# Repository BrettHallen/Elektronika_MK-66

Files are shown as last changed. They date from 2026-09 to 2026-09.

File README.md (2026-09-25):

# Elektronika MK-66<br>Электроника МК-66
Information about the Soviet-era engineering "microcalculator".<br>

Processor: [К145ИП16Б](/K145IP16B/)<br>
Display: [ИЛЦ2-12/8Л](/ILC2-12_8L)<br>
Keypad: 5x5 metal-dome matrix<br>

## DEAR COMRADE!
You are now the owner of a domestically made microcalculator.<br>
A microcalculator is a miniature electronic computing device for personal use.<br>
Careful handling of the microcalculator, tidiness and compliance with the requirements of this operating manual will ensure its reliable operation for a long time.<br>
We are confident that the microcalculator will be a reliable helper in your mathematical calculations.<br>
The manufacturer’s engineers are continually working to improve the technical and operating characteristics of the microcalculator and will be grateful for your feedback on its performance.<br>

## Keypad Layout

The MK-66 has 25 keys in a 5 × 5 matrix, plus two slide switches above the keys. Each key has a **primary function**, printed on the key, and a *second function*, printed on the panel above it. To use a second function, press **F** first, then the key.

### Switches

| Position | Marking | Function |
|:--|:--|:--|
| Left | `•` | **Power**: slide right (towards the dot) for on, left for off |
| Right | `Г` / `Р` | **Angle mode**: Г = degrees (*градусы*), Р = radians (*радианы*). MK-66 only; the MK-66A works in degrees only |

### Original markings

Each cell shows the *second function* above the **key**.

| | Col 1 | Col 2 | Col 3 | Col 4 | Col 5 |
|:-:|:-:|:-:|:-:|:-:|:-:|
| **Row 1** | *CF*<br>**C** | *1/X*<br>**/-/** | &nbsp;<br>**arc** | &nbsp;<br>**ВП** | &nbsp;<br>**F** |
| **Row 2** | *eˣ*<br>**7** | *10ˣ*<br>**8** | *yˣ*<br>**9** | *ЗП*<br>**[(** | *СП*<br>**)]** |
| **Row 3** | *ln*<br>**4** | *lg*<br>**5** | *√*<br>**6** | *П×*<br>**×** | *П÷*<br>**÷** |
| **Row 4** | *sin*<br>**1** | *cos*<br>**2** | *tg*<br>**3** | *П+*<br>**+** | *П−*<br>**−** |
| **Row 5** | *Р→Г*<br>**0** | *Г→Р*<br>**.** | *n!*<br>**π** | *Х↔П*<br>**↔** | *ИП*<br>**=** |

### English equivalents

| | Col 1 | Col 2 | Col 3 | Col 4 | Col 5 |
|:-:|:-:|:-:|:-:|:-:|:-:|
| **Row 1** | *Cancel F*<br>**Clear** | *1/x*<br>**+/−** | &nbsp;<br>**Inverse (arc)** | &nbsp;<br>**EE / EXP** | &nbsp;<br>**Function** |
| **Row 2** | *eˣ*<br>**7** | *10ˣ*<br>**8** | *yˣ*<br>**9** | *MS*<br>**(** | *MC*<br>**)** |
| **Row 3** | *ln*<br>**4** | *log*<br>**5** | *√x*<br>**6** | *M×*<br>**×** | *M÷*<br>**÷** |
| **Row 4** | *sin*<br>**1** | *cos*<br>**2** | *tan*<br>**3** | *M+*<br>**+** | *M−*<br>**−** |
| **Row 5** | *rad→deg*<br>**0** | *deg→rad*<br>**.** | *n!*<br>**π** | *X↔M*<br>**X↔Y** | *MR*<br>**=** |

### Key reference

| Marking | Russian | English | Notes |
|:--|:--|:--|:--|
| **C** | — | Clear | Once: clears overflow. In F mode, press 3×: cancel F, clear display, clear constant register. Does not clear memory |
| *CF* | — | Cancel F | Leaves dual-function mode |
| **/-/** | — | Change sign (+/−) | Changes the sign of the mantissa, or of the exponent after **ВП** |
| *1/X* | — | Reciprocal | |
| **arc** | — | Inverse trig prefix | **arc** then *sin*, *cos* or *tg* gives arcsin, arccos, arctan |
| **ВП** | *Ввод порядка*, "enter exponent" | EE / EXP | |
| **F** | — | Function (shift) | Selects the second function of the next key |
| **[(** / **)]** | — | Brackets | Two levels of nesting |
| *ЗП* | *Запись в память*, "write to memory" | MS (memory store) | |
| *СП* | *Сброс памяти*, "reset memory" | MC (memory clear) | |
| *ИП* | *Извлечение из памяти*, "recall from memory" | MR (memory recall) | |
| *П+ П− П× П÷* | П = *Память*, "memory" | M+ M− M× M÷ | Result goes to memory; display is unchanged |
| *Х↔П* | *Обмен Х с памятью*, "exchange X with memory" | X↔M | Swaps display and memory |
| **↔** | — | X↔Y | Swaps display and constant (operand) register |
| *tg* | *Тангенс* | tan | |
| *lg* | *Десятичный логарифм* | log₁₀ | |
| *Р→Г* | *Радианы → Градусы* | rad → deg | |
| *Г→Р* | *Градусы → Радианы* | deg → rad | |
| **π** | — | Pi | Displays 3.1415926 |
| *n!* | — | Factorial | Integers 1–69; n = 69 takes up to 10 s |

> **Note:** Key and switch markings are transcribed from an MK-66 unit. The MK-66A works in degrees only, so its trig functions don't use a Г/Р setting.

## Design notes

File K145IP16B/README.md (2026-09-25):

# К145ИП16Б<br>K145IP16B

Single-chip calculator LSI used in the Soviet *Elektronika* **MK-35** and **MK-66 / MK-66A** microcalculators. It contains the arithmetic unit, control logic, keyboard scanning and the display drivers, and works directly with the **ИЛЦ2-12/8Л** 12-position vacuum-fluorescent display.

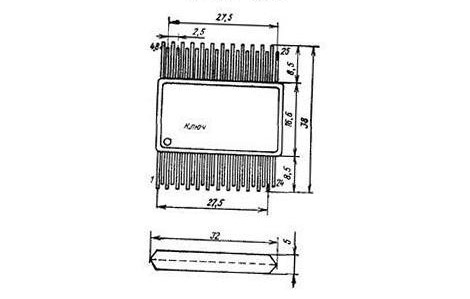
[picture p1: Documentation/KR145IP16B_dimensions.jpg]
Chip dimensions


Display format: 12 positions = mantissa sign + 8 mantissa digits + exponent sign + 2 exponent digits.

---

## Variants and packages

| Marking | Package | Used in |
|:--|:--|:--|
| К145ИП16 | 48-lead flat pack | Б3-35 |
| К145ИП16Б / КР145ИП16Б | 48-lead flat pack | МК-35, МК-66 |
| КР145ИП16В | standard DIP (rare) | — |

**The pinout on this page is for the 48-lead part.** The DIP version is a different, rarely seen package, and its pin numbering does not correspond to the numbering used here.

The 48-lead package is a flat rectangular body with fine leads along both long sides, 24 per side, with an index mark ("ключ") at pin 1. This is the package drawn on the MK-35 schematic and the one fitted to MK-66 units.

**МК-66 was built with either chip.** According to the 155la3.ru museum page, К145ИП15А and К145ИП16Б were fitted interchangeably in the MK-66 production run, and the functional difference between К145ИП15 and К145ИП16 is not documented. This is why an MK-66 schematic may be lettered К145ИП15 while the chip on the board is a КР145ИП16Б — the two are drop-in equivalents in this circuit.

---

## Pinout

Signal names below are transcribed from the **MK-35 schematic**, which is the only one of the two sheets that names the nets (column *Цепь*). Pin numbers are from the same sheet.

### Display drive — mantissa (*МАНТИССА*)

Digit/grid strobes. **Р** = *разряд*, "digit position".

| Pin | Original | Function |
|--:|:--|:--|
| 40 | − | Mantissa sign position |
| 39 | 1Р | Mantissa digit 1 |
| 38 | 2Р | Mantissa digit 2 |
| 37 | 3Р | Mantissa digit 3 |
| 36 | 4Р | Mantissa digit 4 |
| 35 | 5Р | Mantissa digit 5 |
| 34 | 6Р | Mantissa digit 6 |
| 33 | 7Р | Mantissa digit 7 |
| 32 | 8Р | Mantissa digit 8 |

### Display drive — exponent (*ПОРЯДОК*)

| Pin | Original | Function |
|--:|:--|:--|
| 41 | − | Exponent sign position |
| 44 | 1Р | Exponent digit 1 |
| 42 | 2Р | Exponent digit 2 |

### Display drive — segments (*СЕГМЕНТЫ*)

| Pin | Original | Segment |
|--:|:--|:--|
| 20 | а | a — top |
| 23 | б | f — top left |
| 29 | в | b — top right |
| 28 | г | g — middle |
| 25 | д | e — bottom left |
| 27 | е | c — bottom right |
| 26 | ж | d — bottom |
| 30 | и | decimal point |

Russian segment lettering on this display is **not** the ГОСТ a–g ordering: а is the top bar, б and в the upper left and upper right, г the middle bar, д and е the lower left and lower right, ж the bottom bar, and и the decimal point. The MK-35 sheet's *Расположение анодов HG1* diagram and the MK-66 sheet's Western-lettered equivalent both show this arrangement.

### Keyboard inputs

| Pin | Original | Function |
|--:|:--|:--|
| 8 | инф. вход 1 | Information (data) input 1 |
| 9 | инф. вход 2 | Information (data) input 2 |
| 10 | инф. вход 3 | Information (data) input 3 |
| 11 | инф. вход 4 | Information (data) input 4 |
| 18 | инф. вход 5 | Information (data) input 5 |

The keyboard is a matrix scanned by the same digit strobes that drive the display, and read back on these five inputs.

### Clock, power and control

| Pin | Original | Function |
|--:|:--|:--|
| 2 | контр. fт | Clock frequency test point (fт = *тактовая частота*, clock frequency) |
| 4 | контр. fт | Clock frequency test point |
| 5 | Rf | Clock-frequency setting resistor (R24 in the MK-35: 68 k / 82 k / 120 k selected on test) |
| 7 | Uп | Supply voltage (*напряжение питания*) |
| 12 | Уст. "0" | Set to zero — reset |
| 13 | Корпус | Common / case (ground) |
| 16 | Ускор. ввод | "Accelerated input" — see notes |
| 31 | Корпус | Common / case (ground) |
| 46 | рад./град. | Radian / degree select, driven by switch SA2 |

Pins not listed above are not named on either schematic.

---

## Notes from the MK-35 schematic

- *"Rf and Uп are set in accordance with the parameters of chip D1"* — the resistors at pins 5 and 7 are selected per individual chip, not fixed values.
- Switch positions for the documented measurements: SA1 = On, SA2 = "Degrees".
- Operating conditions were measured with a В7-27А voltmeter at a microcalculator supply of −5 V, tolerance ±10 %.
- Waveforms 1–20, 22 and 23 were measured with respect to the positive terminal of the supply, using a С1-76 oscilloscope. Waveforms 13–20 were taken while the display showed **−9.1415926 −87**, which is a useful reference pattern when probing the digit and segment lines.

---

## Uncertainties

- **Pin 16, *Ускор. ввод*.** Literally "accelerated input". On the MK-35 sheet it sits on the same node as the supply capacitors and the ground pins, so it may be supply-related rather than a functional input. Not verified against a datasheet.
- **Pins 2 and 4, *контр. fт*.** Named as clock-frequency monitoring points; whether they are the oscillator's own RC pins or buffered test outputs is not stated on the sheet.

## What the MK-66 schematic shows

The MK-66 sheet gives no net names for D1 — only pin numbers — so it cannot confirm the groupings above. Two things are worth recording:

- D1 is lettered **"К145 ИП15"** on that drawing, not ИП16Б. This is not an error: both chips were fitted to MK-66 boards interchangeably (see *Variants and packages* above).
- The pins shown along the top edge of D1 (display side), left to right, are: 40, 19, 20, 21, 22, 23, 24, 25, 26, 39, 38, 37, 36, 35, 34, 33, 32, 30, 29, 28, 27. The band 19–26 is wider than the segment group on the MK-35 sheet, which suggests the exponent positions may be on different pins in this design — or that 19, 21, 22 and 24 are misreadings of a faint scan.
- The keypad block's own connector numbering is 1–13: columns 7, 8, 9, 10, 11; rows 1, 3, 4, 5, 6; the power switch SA1 on 2; the degree/radian switch SA2 on 12 and 13. These are keypad terminal numbers, not chip pins.

## Electrical parameters

Published for **К145ИП15**, the equivalent chip fitted alongside ИП16Б in the MK-66. Treat as indicative for ИП16Б until confirmed.

| Parameter | Value |
|:--|:--|
| Supply current | ≤ 5 mA |
| Digit (grid) outputs, logic 0 | ≤ −25.2 V |
| Digit (grid) outputs, logic 1 | ≥ −1.0 V |
| Segment outputs, logic 0 | ≤ −25.2 V |
| Segment outputs, logic 1 | ≥ −1.0 V |
| Clock generator, logic 0 | ≤ −11 V |
| Clock generator, logic 1 | ≥ −1.0 V |
| Supply Uип1 | −14.0 … −16.5 V |
| Supply Uип2 | ≥ −30 V |

Note that all logic levels are negative with respect to the case, so measurements should be referenced to the case, not to the battery negative.

Manufacturers: Voronezh ZPP (PO "Elektronika") and its subsidiary plant "Deviz" (Alekseyevka, Belgorod region).

## Sources

- *Схема электрическая принципиальная микрокалькулятора "Электроника МК35"* — pin/net table for D1 КР145ИП16Б.
- *Схема электрическая принципиальная микрокалькулятора "Электроника МК 66"* — pin numbers only.
- [155la3.ru — 145 series](http://www.155la3.ru/k145_3.htm) — variants, packages, manufacturers, and the К145ИП15 electrical parameters.

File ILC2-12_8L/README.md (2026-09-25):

# ИЛЦ2-12/8Л<br>ILC2-12/8L

Vacuum fluorescent display used in the *Elektronika* **MK-35** and **MK-66 / MK-66A** microcalculators, driven directly by the К145ИП16Б / К145ИП15А calculator chip.

Twelve-digit single-colour (green) segmented display for digits 0–9 with a decimal point after each position. Multiplexed drive. Flat glass envelope with 22 leads, brought out from the two opposite long sides. Horizontal working position, mass 20 g. Listed Western analogue: **11-ST-24**.

> **Lead numbering:** counted left to right along the bottom row, and right to left along the top row, viewed from the front of the display.

## Main parameters

| Parameter | Value |
|:--|:--|
| Display type / colour | Numeric / green |
| Number of digit positions | 12 |
| Information field, mm | 5 × 45 |
| Digit position, mm | 2.4 × 4.3 |
| Luminous area, one digit / total, mm² | 2.2 / 26.4 |
| Number of controlled elements | 88 |
| Viewing angle, ° | 45 |
| Warm-up time, s | ≤ 0.1 |
| Nominal brightness, cd/m² | 700 |
| Brightness non-uniformity, % | 40 |
| Brightness at end of life, cd/m² | 300 |
| Filament voltage, nominal / range, V | 2.4 / 2.15 … 2.9 |
| Filament current, nominal / range, mA | 22 / 20 … 24 |
| Grid cut-off voltage, V | ≤ −1.5 |
| Grid pulse voltage, V | 24 |
| Anode (segment) pulse voltage, V | 24 |
| Grid pulse current, one position, mA | 2 |
| Segment pulse current, one position, mA | 0.75 |
| Filament switching cycles | ≥ 10⁴ |
| Duty ratio (*скважность*) | 10 ± 1 |
| Ambient temperature, °C | −45 … +70 |
| Minimum service life, h | 1000 |

## Pinout

| Pin | Electrode | | Pin | Electrode |
|--:|:--|---|--:|:--|
| 1 | Grid, position 12 | | 12 | Grid, position 1 |
| 2 | Grid, position 11 | | 13 | Cathode |
| 3 | Grid, position 10 | | 14 | Segment **и**, positions 1–12 |
| 4 | Grid, position 9 | | 15 | Segment **е**, positions 1–12 |
| 5 | Grid, position 8 | | 16 | Segment **в**, positions 1–12 |
| 6 | Grid, position 7 | | 17 | Segment **а**, positions 1–12 |
| 7 | Grid, position 6 | | 18 | Segment **б**, positions 1–12 |
| 8 | Grid, position 5 | | 19 | Segment **г**, positions 1–12 |
| 9 | Grid, position 4 | | 20 | Segment **д**, positions 1–12 |
| 10 | Grid, position 3 | | 21 | Segment **ж**, positions 1–12 |
| 11 | Grid, position 2 | | 22 | Cathode, conductive coating on the inner surface of the envelope |

The filament (cathode) runs between pins 13 and 22, with the internal screen coating tied to the pin-22 end. Grids are numbered in reverse to the pins: position 1 is the rightmost digit on pin 12, position 12 the leftmost on pin 1.

## Segment designations

Segment designations

| Russian | Western | Position | Display pin |
|:-:|:-:|:--|--:|
| а | a | top | 17 |
| б | f | top left | 18 |
| в | b | top right | 16 |
| г | g | middle | 19 |
| д | e | bottom left | 20 |
| е | c | bottom right | 15 |
| ж | d | bottom | 21 |
| и | dp | decimal point | 14 |

> **Note:** this is not the ГОСТ a–g ordering that the letters suggest. The Russian letters run а (top), then б and в for the upper left and upper right, г for the middle bar, д and е for the lower left and lower right, and ж for the bottom. In particular **ж is the bottom segment, not the middle**, and **г is the middle**.
>
> Both schematics agree. The MK-35 sheet's *Расположение анодов HG1* diagram draws the letters in place with their pin numbers; the MK-66 sheet's *Расположение сегментов HG* diagram draws the same arrangement using Western letters — A top, F and B upper left and right, M middle, E and C lower left and right, D bottom.

## How the calculator uses it

The twelve positions carry: mantissa sign, 8 mantissa digits, exponent sign, 2 exponent digits — reading left to right on the glass, which is position 12 down to position 1 in the datasheet's numbering.

| Display position | Pin | Shows |
|--:|--:|:--|
| 12 | 1 | Mantissa sign |
| 11 … 4 | 2 … 9 | Mantissa digits 1 … 8 |
| 3 | 10 | Exponent sign |
| 2 | 11 | Exponent digit 1 |
| 1 | 12 | Exponent digit 2 |

## Predicted wiring to the calculator chip

Derived by combining this datasheet with the net names on the MK-35 schematic. **Not yet verified on hardware** — use as a checklist against a real board. Every line runs through a series resistor (180 k in the MK-35; 180 k and 300 k in the MK-66), so expect that resistance rather than a short.

| Display pin | Signal | Chip pin (per MK-35) | Verified |
|--:|:--|--:|:-:|
| 1 | Grid 12 — mantissa sign | 40 | ☐ |
| 2 | Grid 11 — mantissa 1Р | 39 | ☐ |
| 3 | Grid 10 — mantissa 2Р | 38 | ☐ |
| 4 | Grid 9 — mantissa 3Р | 37 | ☐ |
| 5 | Grid 8 — mantissa 4Р | 36 | ☐ |
| 6 | Grid 7 — mantissa 5Р | 35 | ☐ |
| 7 | Grid 6 — mantissa 6Р | 34 | ☐ |
| 8 | Grid 5 — mantissa 7Р | 33 | ☐ |
| 9 | Grid 4 — mantissa 8Р | 32 | ☐ |
| 10 | Grid 3 — exponent sign | 41 | ☐ |
| 11 | Grid 2 — exponent 1Р | 44 | ☐ |
| 12 | Grid 1 — exponent 2Р | 42 | ☐ |
| 13 | Cathode | — (voltage converter) | ☐ |
| 14 | Segment и | 30 | ☐ |
| 15 | Segment е | 27 | ☐ |
| 16 | Segment в | 29 | ☐ |
| 17 | Segment а | 20 | ☐ |
| 18 | Segment б | 23 | ☐ |
| 19 | Segment г | 28 | ☐ |
| 20 | Segment д | 25 | ☐ |
| 21 | Segment ж | 26 | ☐ |
| 22 | Cathode + screen | — (voltage converter) | ☐ |

**The three exponent grids are the ones to check first.** Chip pins 41, 44 and 42 are named on the MK-35 sheet but never appear on the MK-66 sheet, whose chip-side numbering instead includes 19, 21, 22 and 24 — pins the MK-35 sheet does not name. Either the MK-66 scan is misread, or К145ИП15А brings the exponent strobes out on different pins from К145ИП16Б. Display pins 10, 11 and 12 settle it.

## Notes

- The MK-66 schematic's display connections match this datasheet exactly: two cathode pins, eight segments, twelve grids. It is only the chip side of that drawing that carries no signal names.
- The datasheet's count of **88 controlled elements** does not equal 12 positions × 8 elements = 96. The eight missing element sites are most likely on the two sign positions, which only ever show a minus and a decimal point.
- Everything is negative with respect to the calculator's case, so bench measurements should be referenced to the case rather than to the battery negative.

## Sources

- ИЛЦ2-12/8Л datasheet (Russian), including the electrode/lead table.
- *Схема электрическая принципиальная микрокалькулятора "Электроника МК35"* — HG1 pin table and net names.
- *Схема электрическая принципиальная микрокалькулятора "Электроника МК 66"* — display connections.

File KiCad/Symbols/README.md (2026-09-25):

# Kicad Symbols for MK-66

| File | Part |
|---|---|
| ilc2-12_8l | symbol for display |
| k145ip16b  | symbol for arithmetic unit |
| pn-1 | symbol for display power board |

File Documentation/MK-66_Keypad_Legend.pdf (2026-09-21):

# Elektronika MK-66 / MK-66A: Keypad Legend

Key legend is printed on each key. Second function (above the key) is used by pressing F first; CF cancels.

## Original legends

## English equivalents

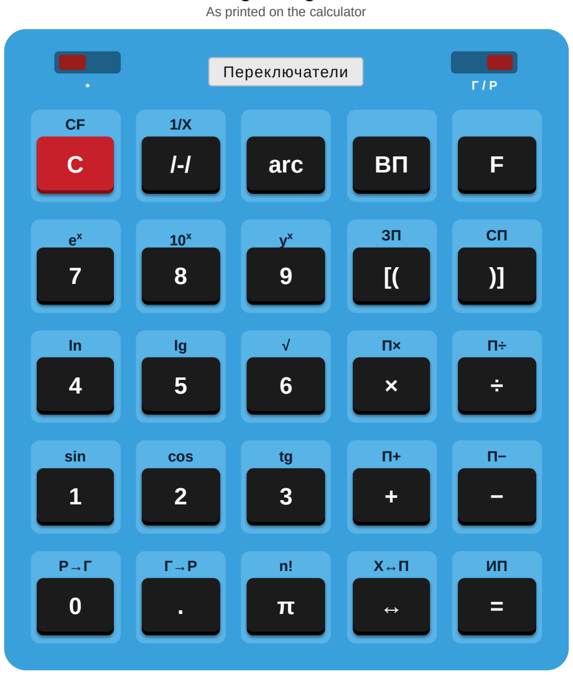
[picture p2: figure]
As printed on the calculator; Переключатели; arc; sin 1; cos 2

ВП – enter exponent · ЗП – store to memory · ИП – recall memory · СП – clear memory · П – memory
- Х↔П – exchange display & memory · Г – degrees · Р – radians · tg – tangent · lg – log₁₀

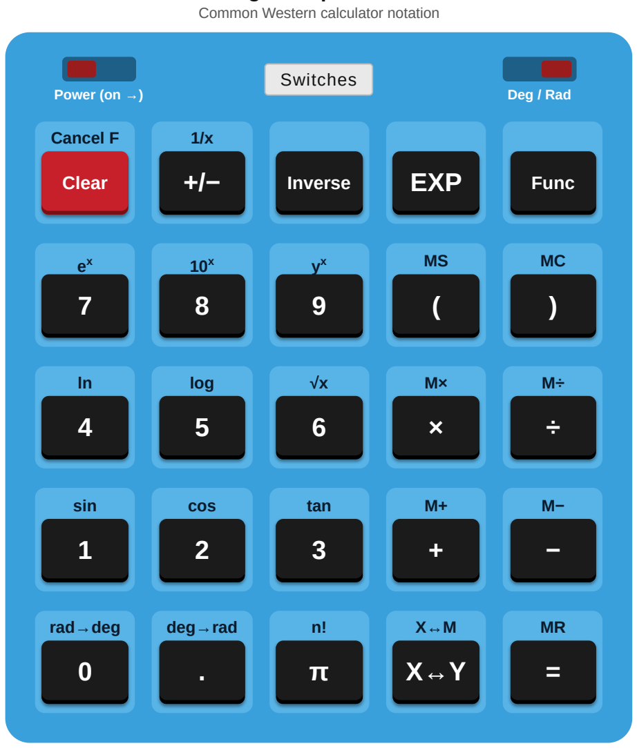
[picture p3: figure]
Common Western calculator notation; Power (on →); Switches; Deg / Rad; Cancel F; Clear; Inverse; EXP; Func; log 5; sin 1; cos 2; tan 3; rad→deg 0; deg→rad .

Inverse (arc) followed by sin/cos/tan gives arcsin/arccos/arctan. X↔Y swaps display and constant register. The MK-66A calculates trig functions in degrees only.

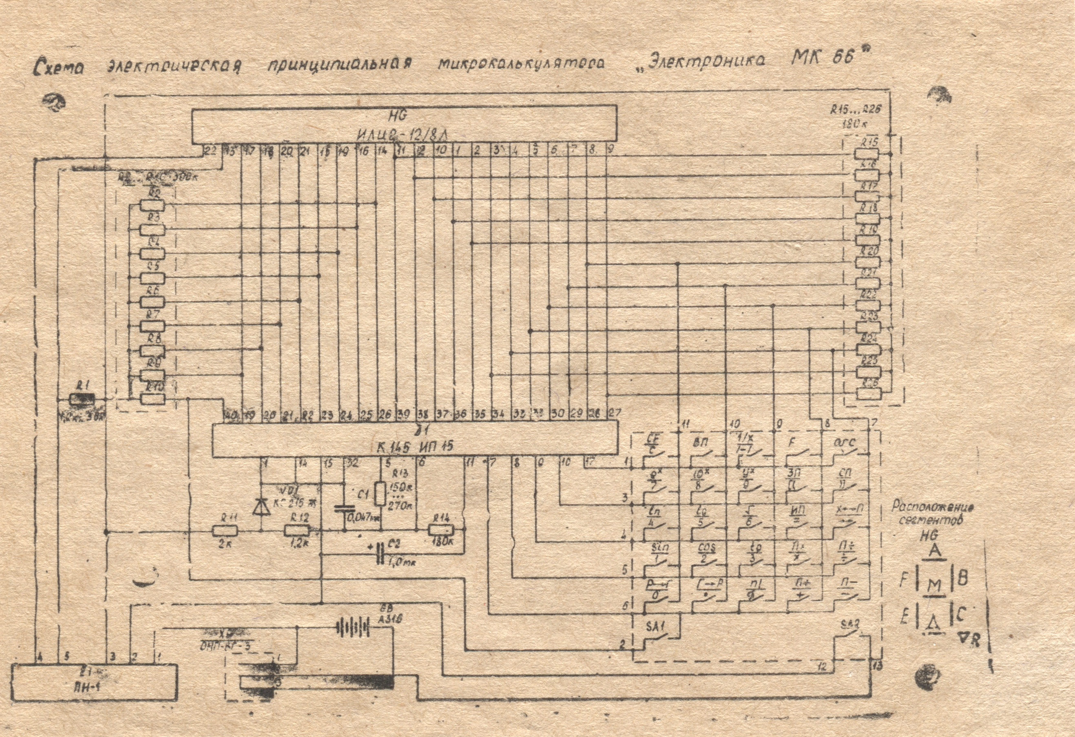
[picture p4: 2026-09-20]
Documentation/Elektronika_MK-66_Schematic.jpg

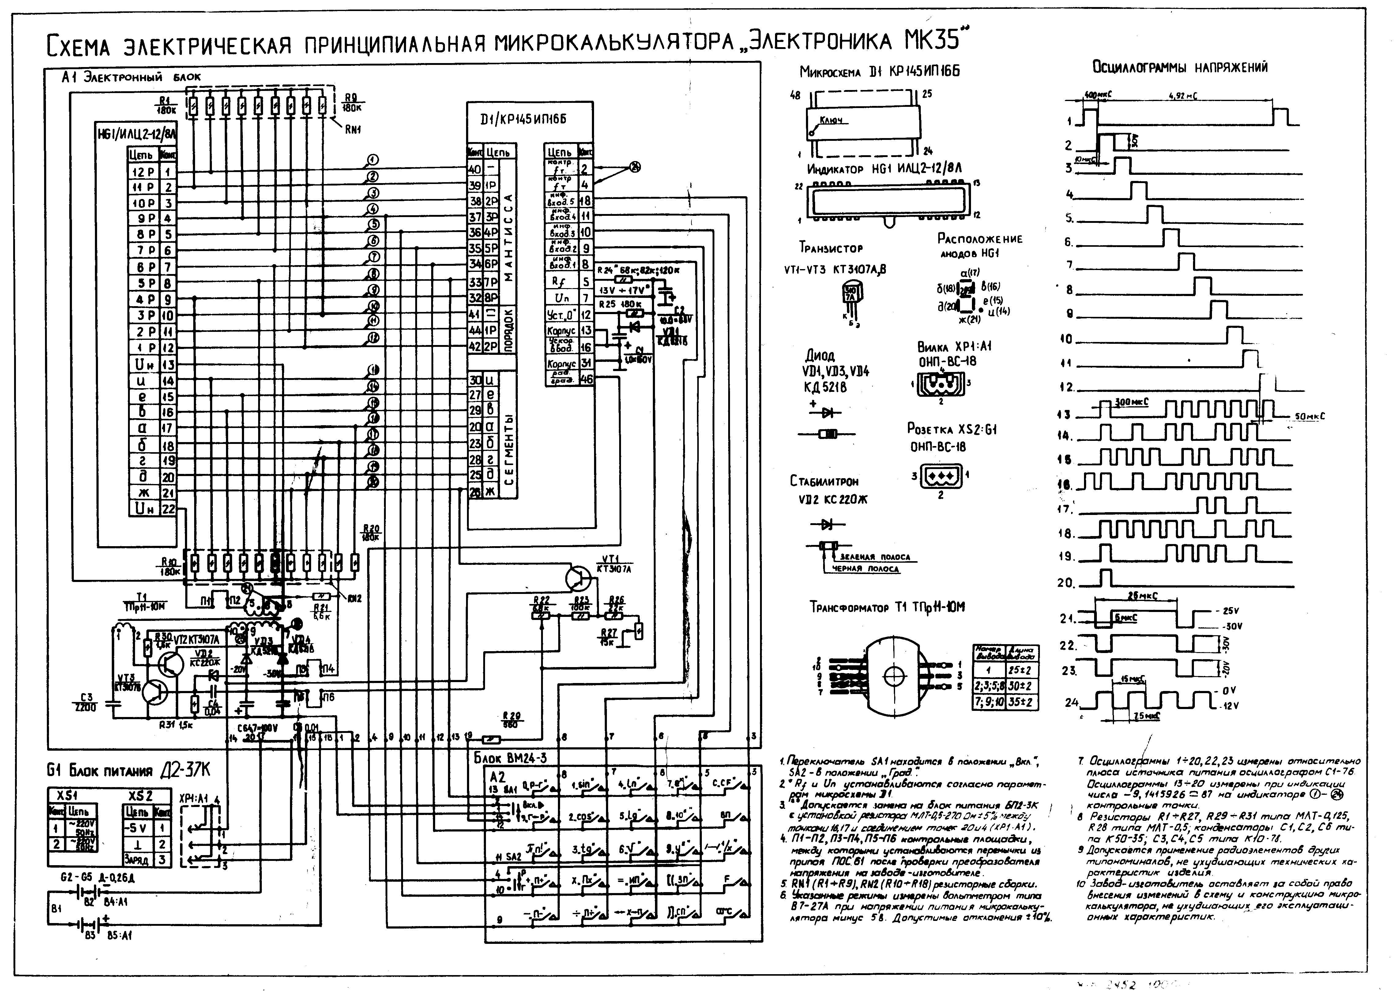
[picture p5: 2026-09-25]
Documentation/Elektronika_MK-35_Schematic.jpeg

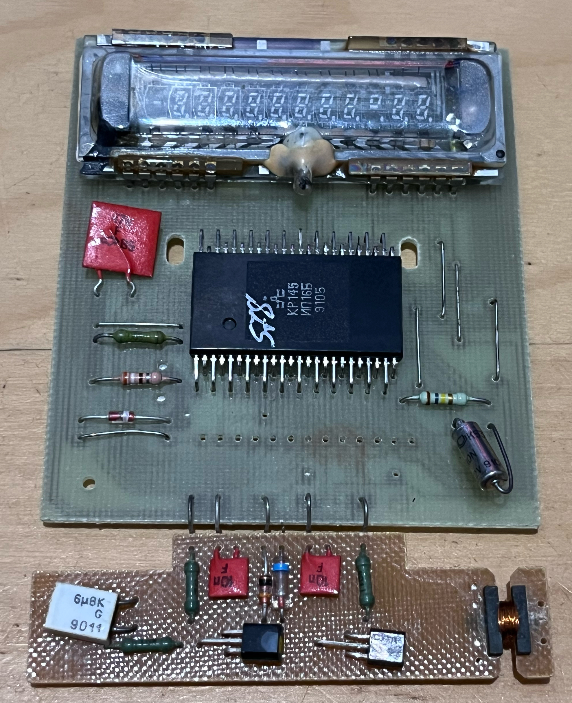
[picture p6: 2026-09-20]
Images/Elektronika_MK-66_PCB1.jpg

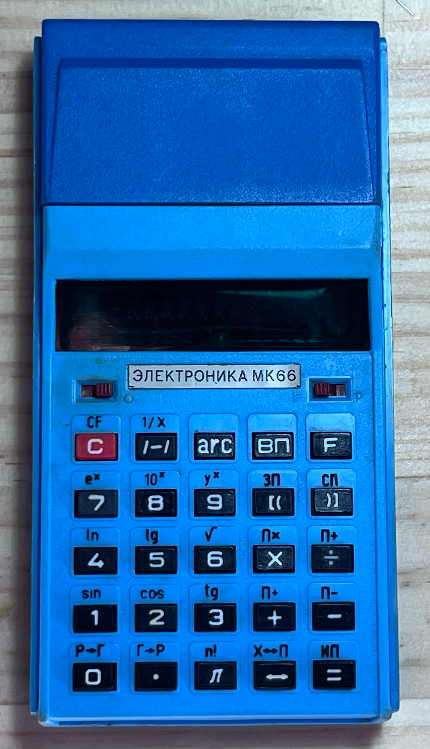
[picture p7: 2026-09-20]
Images/Elektronika_MK-66.jpg

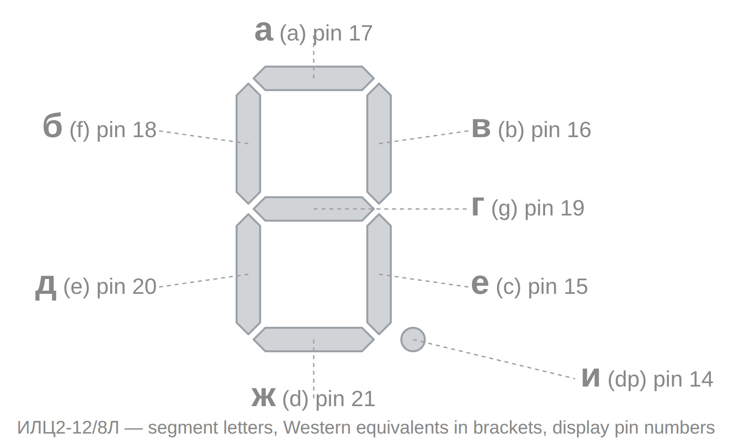
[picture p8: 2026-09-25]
ILC2-12_8L/ILC2-12-8L_segments.jpg

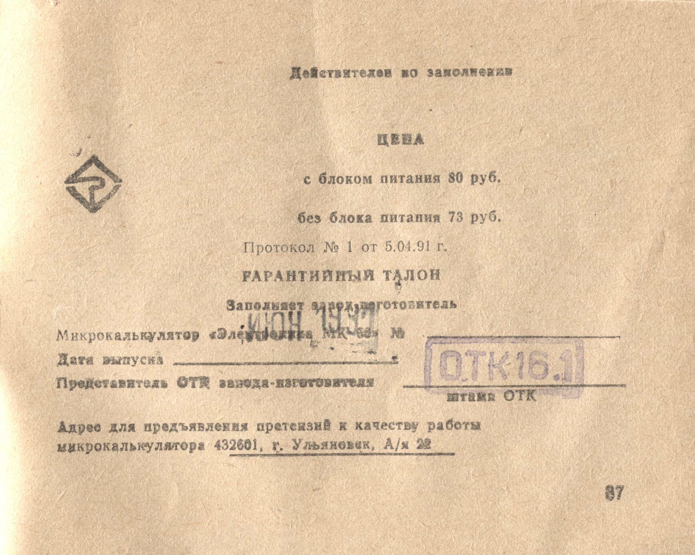
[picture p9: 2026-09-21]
Documentation/Elektronika_MK-66_Warranty_Coupon.jpg

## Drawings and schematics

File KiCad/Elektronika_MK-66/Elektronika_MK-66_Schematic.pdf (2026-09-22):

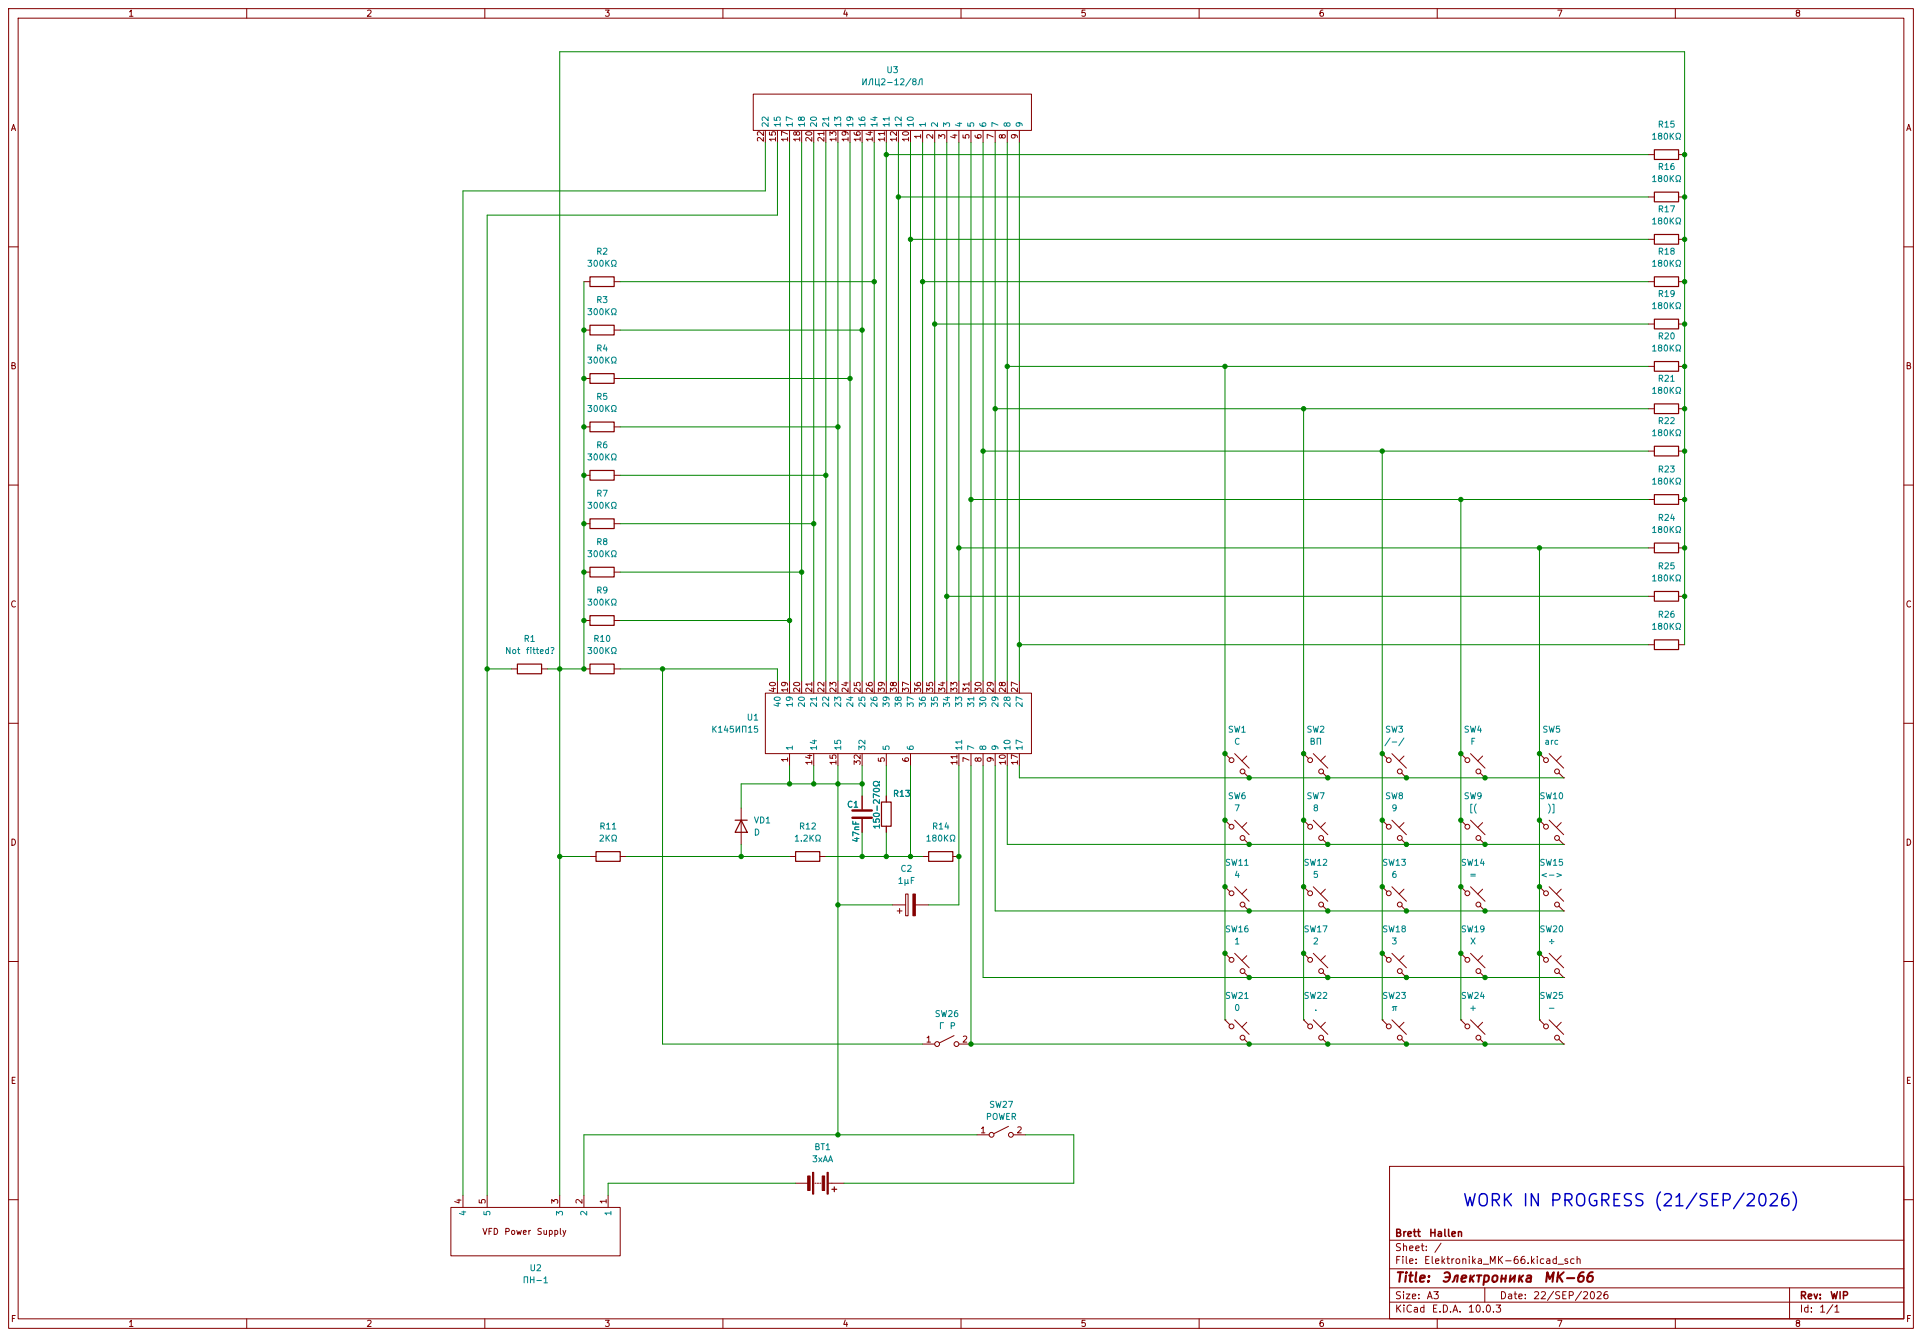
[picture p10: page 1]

SW20 ÷ WORK IN PROGRESS (21/SEP/2026)

Size: A3 | Rev: WIP | F Date: 22/SEP/2026
KiCad E.D.A. 10.0.3 | Id: 1/1

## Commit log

2026-09-21 Work in progress
    [Elektronika_MK-66.kicad_pcb, Elektronika_MK-66.kicad_sch]
2026-09-22 Work in progress
    Original schematic redrawn, needs to be verified against actual board due to unclear "smudges" on original schematic.
    [Elektronika_MK-66.kicad_sch]
2026-09-25 Updating schematic
    I don't trust the MK-66 schema from the manual which lists a К145ИП15 ... working it out from the physical PCB with К145ИП16Б
    [Elektronika_MK-66.kicad_sch]
